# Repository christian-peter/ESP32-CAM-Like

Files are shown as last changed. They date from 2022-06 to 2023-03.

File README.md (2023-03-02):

# ESP32-CAM-Like
ESP32-CAM with more IO

<b>Projet abandonné pour caused de difficultés de soudure du connecteur de caméra.
Toutefois, le proto est fonctionnel.</b>

Ce projet est né du manque d'E/S (GPIO) de la carte ESP32-CAM.

La carte est construite autour d'un ESP32 WROVER. Elle est alimentée sous 5V.
Elle comporte des sorties numériques, des entrées analogiques, une carte microSD et bien sur une caméra (CAMERA_MODEL_AI_THINKER est le seul modèle testé à ce jour).  
Vu le nombre d'E/S nécessaires, tous les périphériques ne sont pas accessibles simultanément.  
Les sorties numériques et les entrées analogiques sont contrôlées par un bus I2C.

Les sorties numériques (PWM/MLI) sont gérées par un PCA9685, alimenté en permanence sous 5V ou 3,3V (pont de soudure 'OUTPUTS').  
le pont de soudure '/OE' doit être à 0 pour que les sorties soient actives.  
Deux sorties de ce circuit ('POWER' et 'POWER_SD') sont utilisées pour sélectionner les périphériques.  
<b>Seule une de ces deux sorties doit être activée.</b>  
Si 'POWER_SD' est au niveau haut, il est possible d'utiliser la carte microSD.  
Si 'POWER' est au niveau haut, il est possible d'utiliser les autres périphériques.  
Ce circuit pilote également deux LEDs (rouge et verte).

Les entrées analogiques sont contrôlées par un MCP3428 (4 canaux).  
Le canal 1 est relié au connecteur 'MAX9814' qui peut recevoir un ampli audio du même nom.  
Le canal 2 est connecté à un LDR polarisée par une résistance R22.  
Le canal 3 permet de mesurer la tension d'alimentation.  
Ces trois premiers canaux sont référencés par rapport à la masse (0V).  
Le 4ème canal est relié au connecteur 'CAN' qui permet une entrée différentielle.  

Les schémas et PCB ont été dessinés avec Eagle.  
Les résistances coté 'bottom' (carte SD) sont inutiles car elles sont remplacées par des résistances de 'pullup' internes à l'ESP32.

Les logiciels sont développés avec l'IDE arduino. Les exemples illustrent :
- l'utilisation de la caméra,
- l'utilisation du CAN (MPC3428)
- l'utilisation de la carte SD.

Les sorties numériques (PCA9685) sont mises en oeuvre dans tous les exemples.

<b>Attention, malheureusement, la caméra ne fonctionne pas lorsqu'une carte carte mémoire est insérée dans le support SD !  </b>

<b>Par contre</b>, il est possible de relier sur le connecteur 'SD-SPI', un module SD SPI de ce type :

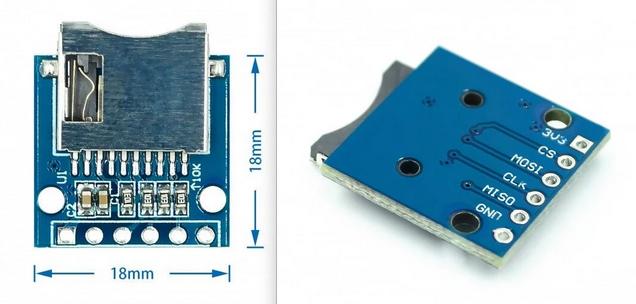
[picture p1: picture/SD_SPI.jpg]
SD_SPI


Celui ci ne bloque pas la caméra. Toutefois, je n'ai pas testé le fonctionnement de ce module SPI pour l'instant. 

N'hésitez pas à partager les logiciels que vous développez, je les rajouterai sur cette page.

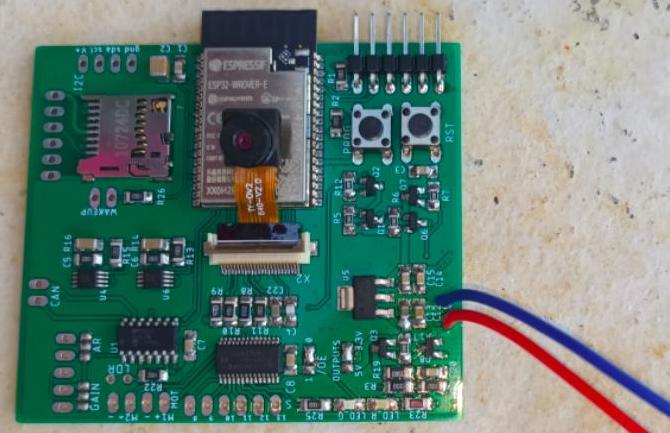
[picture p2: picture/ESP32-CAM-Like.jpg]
ESP32-CAM-Like


Le connecteur en haut à droite permet de programmer l'ESP32 avec cet interface :  
[usb-ftdi232](https://github.com/christian-peter/ruche-connecte/tree/main/usb-ftdi232)  
mais tout interface USB/série fera l'affaire.

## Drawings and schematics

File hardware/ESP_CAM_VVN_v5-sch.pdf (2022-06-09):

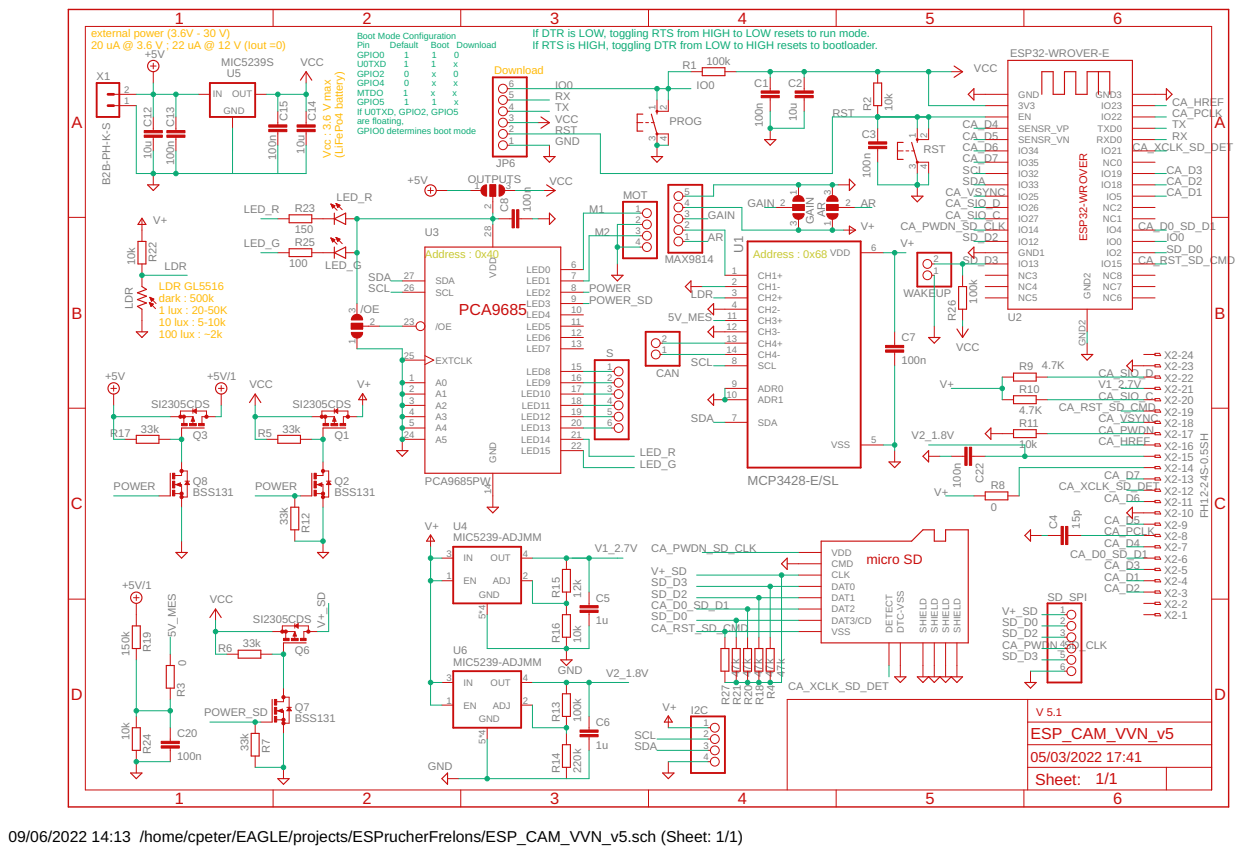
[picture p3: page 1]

If DTR is LOW, toggling RTS from HIGH to LOW resets to run mode.

09/06/2022 14:13 /home/cpeter/EAGLE/projects/ESPrucherFrelons/ESP_CAM_VVN_v5.sch (Sheet: 1/1)

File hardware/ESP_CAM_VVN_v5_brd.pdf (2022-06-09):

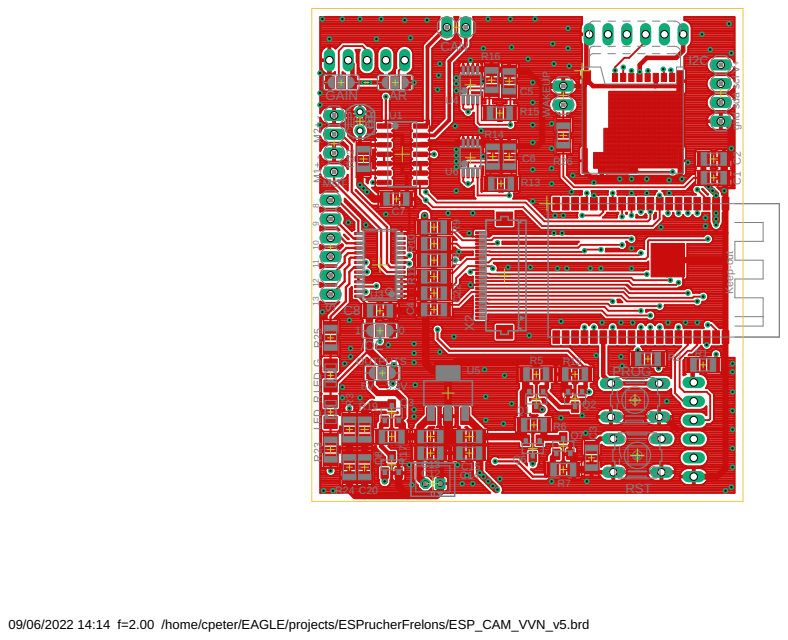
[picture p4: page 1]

09/06/2022 14:14 f=2.00 /home/cpeter/EAGLE/projects/ESPrucherFrelons/ESP_CAM_VVN_v5.brd

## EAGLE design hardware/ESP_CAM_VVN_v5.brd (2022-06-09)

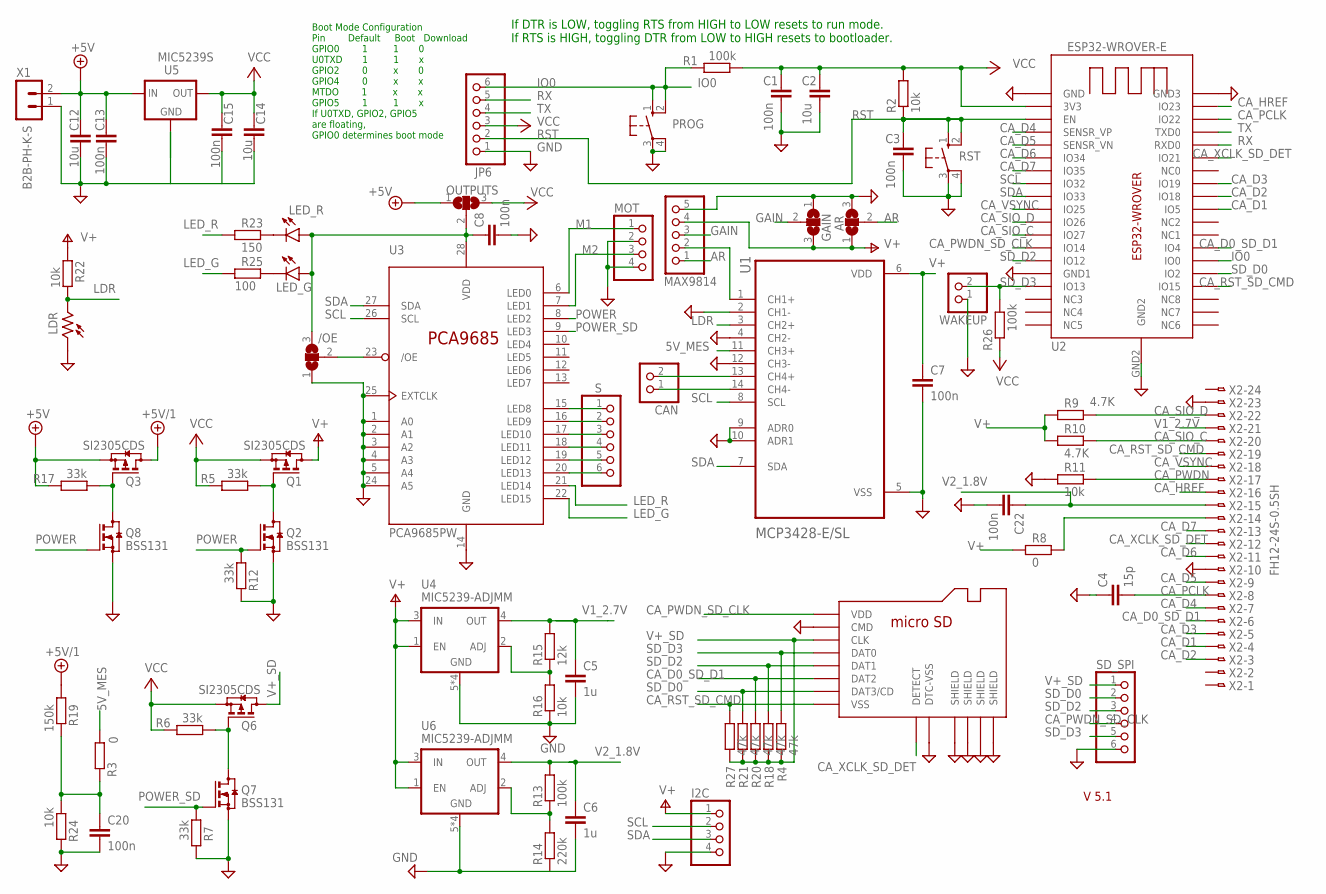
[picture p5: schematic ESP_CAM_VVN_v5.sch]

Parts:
/OE: SJ2W; SJ_2
AR: SJ2W; SJ_2
C1, C3, C7, C8, C13, C15, C20, C22: 100n; C1206
C2, C12, C14: 10u; C1206
C4: 15p; C1206
C5, C6: 1u; C1206
CAN: PINHD-1X2; 1X02
GAIN: SJ2W; SJ_2
I2C: PINHD-1X4; 1X04
JP6: PINHD-1X6/90; 1X06/90
LDR: VT93N2; VT900
LED_G: LEDSMT1206; 1206
LED_R: LEDSMT1206; 1206
MAX9814: PINHD-1X5; 1X05
MOT: PINHD-1X4; 1X04
OUTPUTS: SJ2W; SJ_2
PROG: 10-XX; B3F-10XX
Q1, Q3, Q6: SI2305CDS; SOT23
Q2, Q7, Q8: BSS131; SOT23
R1, R13, R26: 100k; R1206
R2, R11, R16, R22, R24: 10k; R1206
R3, R8: 0; R1206
R4, R18, R20, R21, R27: 47k; R0805
R5, R6, R7, R12, R17: 33k; R1206
R9, R10: 4.7K; R1206
R14: 220k; R1206
R15: 12k; R1206
R19: 150k; R1206
R23: 150; R1206
R25: 100; R1206
RST: 10-XX; B3F-10XX
S: PINHD-1X6; 1X06
SD1: MICRO-SD-8; MICROSDMOLEX
SD_SPI: PINHD-1X6; 1X06
U1: MCP3428-E/SL; SOIC127P600X175-14N
U2: ESP32-WROVER-E; ESP32-WROVER
U3: PCA9685PW; TSSOP28
U4, U6: MIC5239-ADJMM; MSOP08
U5: MIC5239S; SOT223
WAKEUP: PINHD-1X2; 1X02
X1: B2B-PH-K-S
X2: FH12-24S-0.5SH

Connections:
5V_MES: R3.1, U1.11 (CH3+)
+5V: C12.1, C13.1, OUTPUTS.1, Q3.2 (S), R17.2, U5.1 (IN), X1.2
+5V/1: Q3.3 (D), R19.1
AR: AR.2, MAX9814.1
CA_D0_SD_D1: R20.2, SD1.P$1 (DAT2), U2.IO4, X2.6
CA_D1: U2.IO5, X2.4
CA_D2: U2.IO18, X2.3
CA_D3: U2.IO19, X2.5
CA_D4: U2.SENSOR_VP (SENSR_VP), X2.7
CA_D5: U2.SENSOR_VN (SENSR_VN), X2.9
CA_D6: U2.IO34, X2.11
CA_D7: U2.IO35, X2.13
CA_HREF: U2.IO23, X2.16
CA_PCLK: C4.2, U2.IO22, X2.8
CA_PWDN: R11.2, X2.17
CA_PWDN_SD_CLK: SD1.P$4 (VDD), SD_SPI.4, U2.IO14
CA_RST_SD_CMD: R27.2, SD1.P$6 (VSS), U2.IO15, X2.19
CA_SIO_C: R10.2, U2.IO27, X2.20
CA_SIO_D: R9.2, U2.IO26, X2.22
CA_VSYNC: U2.IO25, X2.18
CA_XCLK_SD_DET: SD1.P$14 (DETECT), U2.IO21, X2.12
GAIN: GAIN.2, MAX9814.3
GND: /OE.1, AR.3, C1.2, C2.2, C3.2, C4.1, C5.2, C6.2, C7.2, C8.2, C12.2, C13.2, C14.2, C15.2, C20.2, C22.2, GAIN.1, I2C.4, JP6.1, LDR.1, MAX9814.5, MOT.2, MOT.4, PROG.3, PROG.4 (P1), Q2.2 (S), Q7.2 (S), Q8.2 (S), R7.2, R11.1, R12.2, R14.1, R16.1, R24.2, RST.3, RST.4 (P1), SD1.P$3 (CMD), SD1.P$9 (SHIELD), SD1.P$10 (SHIELD), SD1.P$11 (SHIELD), SD1.P$12 (SHIELD), SD1.P$13 (DTC-VSS), SD_SPI.6, U1.2 (CH1-), U1.4 (CH2-), U1.5 (VSS), U1.9 (ADR0), U1.10 (ADR1), U1.12 (CH3-), U2.GND, U2.GND1, U2.GND2, U2.GND3, U3.1 (A0), U3.2 (A1), U3.3 (A2), U3.4 (A3), U3.5 (A4), U3.14 (GND), U3.24 (A5), U3.25 (EXTCLK), U4.5 (GND), U4.6 (GND), U4.7 (GND), U4.8 (GND), U5.2 (GND), U5.4 (GND), U6.5 (GND), U6.6 (GND), U6.7 (GND), U6.8 (GND), WAKEUP.1, X1.1, X2.10, X2.23
IO0: JP6.6, PROG.1 (S), PROG.2 (S1), R1.2, U2.IO0
LDR: LDR.2, R22.2, U1.3 (CH2+)
LED_G: R25.1, U3.22 (LED15)
LED_R: R23.1, U3.21 (LED14)
M1: MOT.1, U3.6 (LED0)
M2: MOT.3, U3.7 (LED1)
unnamed: Q1.1 (G), Q2.3 (D), R5.1
unnamed: MAX9814.2, U1.1 (CH1+)
unnamed: C20.1, R3.2, R19.2, R24.1
unnamed: /OE.3, C8.1, LED_G.A, LED_R.A, OUTPUTS.2, U3.28 (VDD)
unnamed: CAN.2, U1.13 (CH4+)
unnamed: Q6.1 (G), Q7.3 (D), R6.1
unnamed: LED_R.C, R23.2
unnamed: LED_G.C, R25.2
unnamed: Q3.1 (G), Q8.3 (D), R17.1
unnamed: R8.2, X2.14
unnamed: CAN.1, U1.14 (CH4-)
unnamed: S.1, U3.15 (LED8)
unnamed: S.2, U3.16 (LED9)
unnamed: S.3, U3.17 (LED10)
unnamed: S.4, U3.18 (LED11)
unnamed: S.5, U3.19 (LED12)
unnamed: S.6, U3.20 (LED13)
unnamed: R13.1, R14.2, U6.2 (ADJ)
unnamed: R15.1, R16.2, U4.2 (ADJ)
OE: /OE.2, U3.23 (/OE)
POWER: Q2.1 (G), Q8.1 (G), R12.1, U3.8 (LED2)
POWER_SD: Q7.1 (G), R7.1, U3.9 (LED3)
RST: C3.1, JP6.2, R2.1, RST.1 (S), RST.2 (S1), U2.EN
RX: JP6.5, U2.RXD0
SCL: I2C.2, U1.8 (SCL), U2.IO32, U3.26 (SCL)
SDA: I2C.3, U1.7 (SDA), U2.IO33, U3.27 (SDA)
SD_D0: R21.2, SD1.P$2 (DAT3/CD), SD_SPI.2, U2.IO2
SD_D2: R18.2, SD1.P$8 (DAT1), SD_SPI.3, U2.IO12
SD_D3: R4.2, R26.2, SD1.P$7 (DAT0), SD_SPI.5, U2.IO13, WAKEUP.2
TX: JP6.4, U2.TXD0
V1_2.7V: C5.1, R15.2, U4.4 (OUT), X2.21
V2_1.8V: C6.1, C22.1, R13.2, U6.4 (OUT), X2.15
V+: AR.1, C7.1, GAIN.3, I2C.1, MAX9814.4, Q1.3 (D), R8.1, R9.1, R10.1, R22.1, U1.6 (VDD), U4.1 (EN), U4.3 (IN), U6.1 (EN), U6.3 (IN)
V+_SD: Q6.3 (D), R4.1, R18.1, R20.1, R21.1, R27.1, SD1.P$5 (CLK), SD_SPI.1
VCC: C1.1, C2.1, C14.1, C15.1, JP6.3, OUTPUTS.3, Q1.2 (S), Q6.2 (S), R1.1, R2.2, R5.2, R6.2, R26.1, U2.VDD33 (3V3), U5.3 (OUT)

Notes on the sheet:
If DTR is LOW, toggling RTS from HIGH to LOW resets to run mode. If RTS is HIGH, toggling DTR from LOW to HIGH resets to bootloader.
Boot Mode Configuration Pin Default Boot Download GPIO0 1 1 0 U0TXD 1 1 x GPIO2 0 x 0 GPIO4 0 x x MTDO 1 x x GPIO5 1 1 x If U0TXD, GPIO2, GPIO5 are floating, GPIO0 determines boot mode
V 5.1

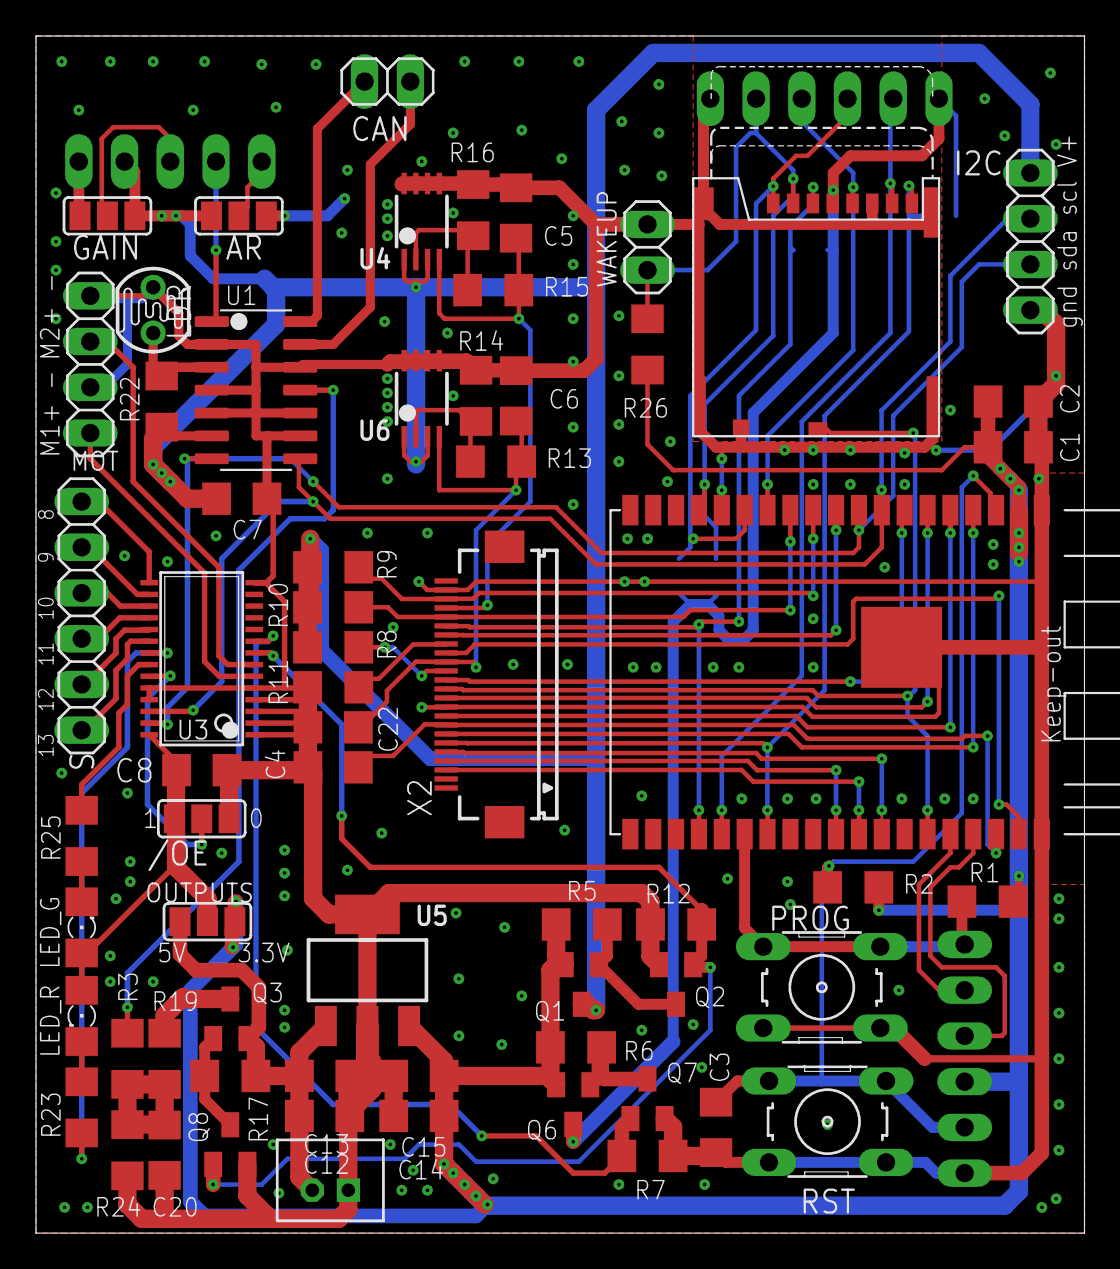
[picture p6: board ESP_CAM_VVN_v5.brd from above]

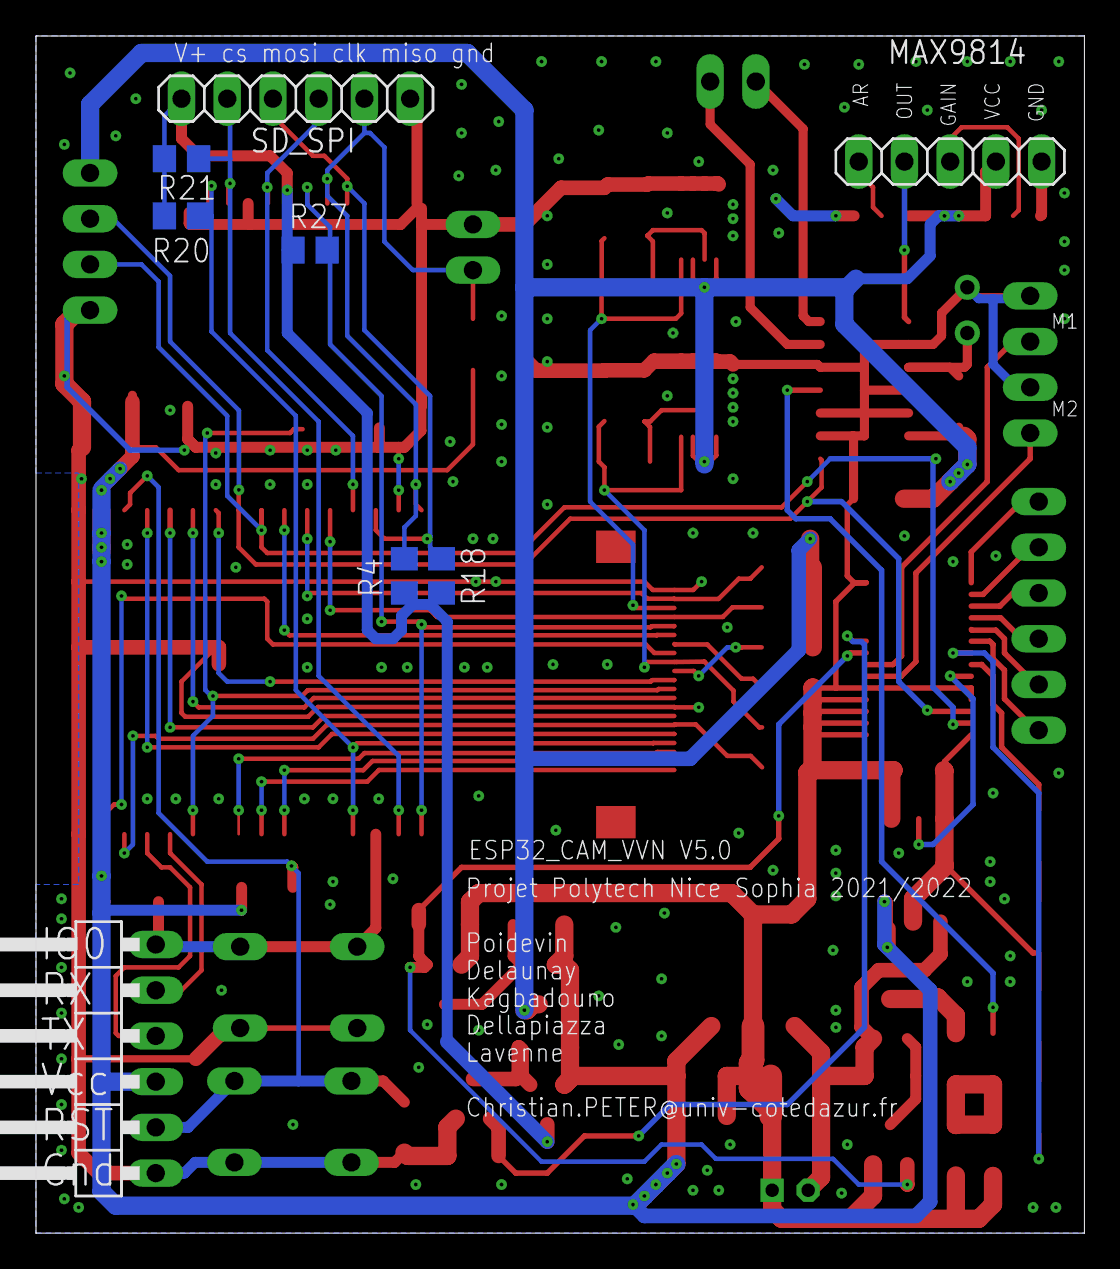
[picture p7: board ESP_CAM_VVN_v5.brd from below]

Board: 2 copper layers, 58.2 x 66.5 mm, 73 parts (8 on the bottom side), 64 nets.

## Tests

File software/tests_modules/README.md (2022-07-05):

<b>Attention les sketch de tests ont été écrits avec la version 1.0.6 d'Espressif Systems.</b>

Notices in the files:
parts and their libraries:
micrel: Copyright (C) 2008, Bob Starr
